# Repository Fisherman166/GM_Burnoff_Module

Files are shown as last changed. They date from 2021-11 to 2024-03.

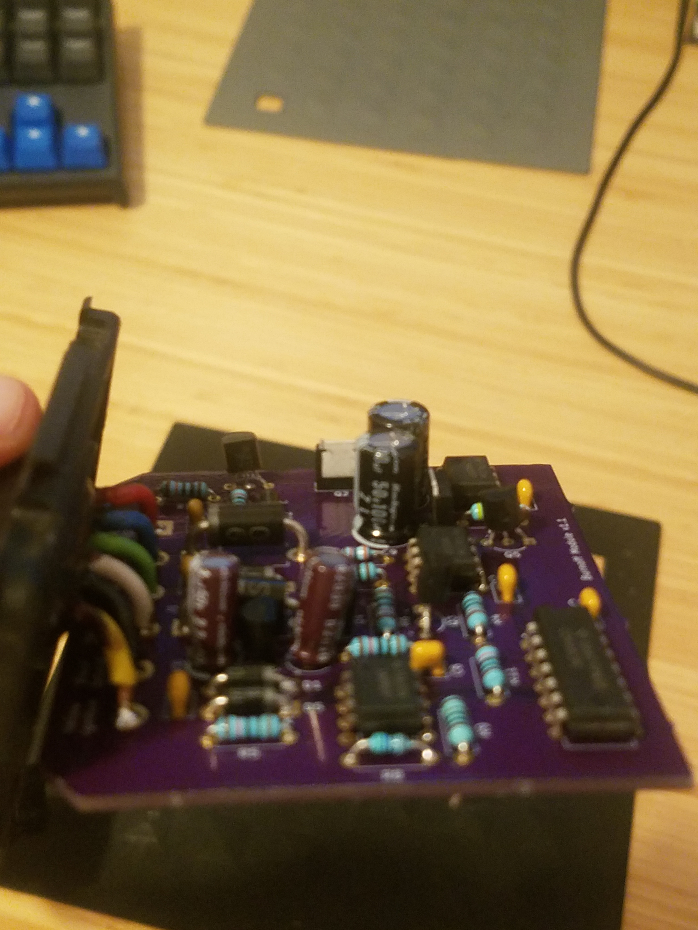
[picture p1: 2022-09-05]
pcb_pictures/20211124_192138.jpg

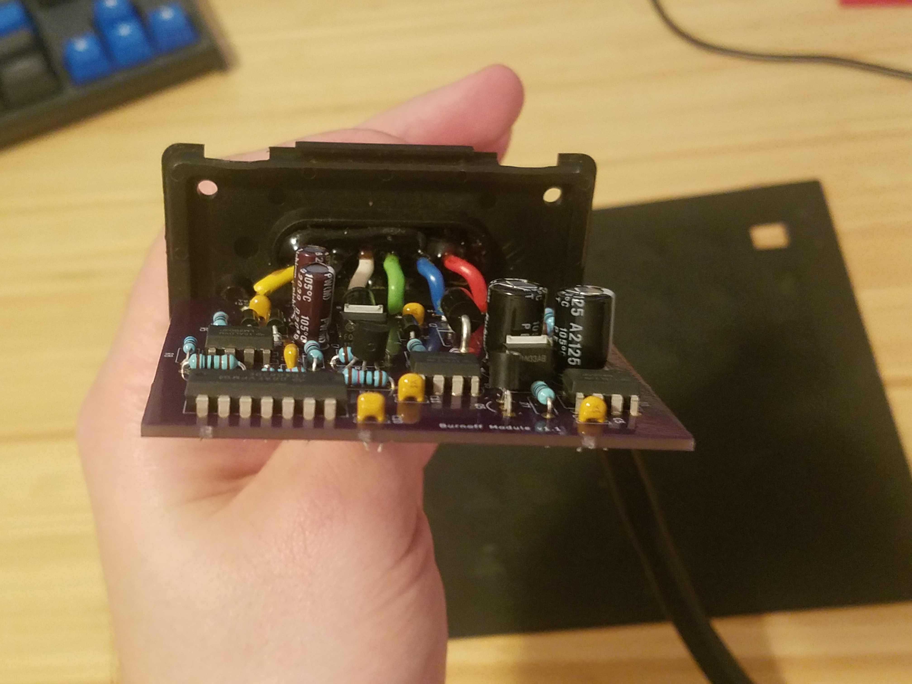
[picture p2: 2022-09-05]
pcb_pictures/20211124_192143.jpg

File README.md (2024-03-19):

# GM Burnoff Module

This repository includes a circuit which mimics the OEM burnoff module functionality. Burnoff modules are found in 1985 GM TPI cars including Corvette, Camaro, and Firebird. Feel free to modify this circuit as you see fit - I don't claim to be an analog eletronics expert.

**NOTE:  As far as I know this circuit should work as intended. Measurements from a working burnoff module in a car and the specifications from the repair manual match the design output. With that said, its never been tested in a real car, and has only been tested on a testbench. So use it at your own risk. I do not take any responsbility for any damage done.**

## Overview
* Building_your_pcb.odt - Tutorial style document which describes how to use this repository to build your own replacement burnoff module.
* OEM_Burnoff_Module_Specification.odt - Document which describes the OEM burnoff module functionality in detail.
* Design_Document.odt - Document which describes both the why and how design decisions were made for the replacement circuit.

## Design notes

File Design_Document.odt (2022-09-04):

Replacement Burnoff Module Design

By: Sean Koppenhafer

# General Information

This circuit was designed for input supply voltages on Battery+ up to 15V. All parts have at least a -40C to 105C temperature rating.

The ignition and serial input pins are protected by standard diodes. The MAF PWR and Burnoff Signal output pins are protected by schottky diodes. Battery+ is protected by the pmos high side switch. Ground is the only pin not protected by a diode or transistor.

All input pins, aside from ground, have a 0.1uF bypass capacitor. All ICs have the same 0.1uF bypass capacitors next to their supplies.

The unused second circuit on the AND gate has all of its inputs tied to ground and its output unconnected.

# PIN F – MAF Power Control

From the OEM spec we know this pin needs to be on whenever the ignition is on, and for roughly five seconds after the ignition is turned off. At a high level this breaks down into a high side switch to control PIN F through a timer circuit. The switch is controlled both by the ignition being being on and some sort of timer that holds the switch on after ignition drops. For the timer circuit a classic IC, the 555 timer, was used.

## High-Side Switching

A high side switch using a pmos and a nmos transistor in combination with a pullup resistor on the pmos gate was used. The circuit controls the gate of the nmos transistor to turn the pmos on/off. The pmos can then supply battery+ (Pin A) to MAF PWR (Pin F) and also provide a switched supply for the rest of the circuit. Using a switched voltage source not just for MAF PWR (Pin F), but for the entire circuit, this design achieves a current draw of 19uA when off according to LTSpice simulation.

The nmos gate is controlled both by ignition (Pin B) and the output of the five second 555 timer. Because the switched supply powers the rest of the circuit, we cannot have a glitch between when ignition (Pin B) goes low and the 555 timer output goes high. To solve this, the 555 timer output and ignition (Pin B) are on at the same time. When ignition (Pin B) goes high, the 555 timer output also goes high. When ignition (Pin B) goes low, the 555 timer keeps the switch on for five seconds before turning the switch off.

## Five Second Timer

After ignition (Pin B) goes from high to low (12V → 0V), we need MAF PWR (Pin F) to stay high for five seconds. A 555 timer is a simple, well-known IC that implements a timer. In the monostable configuration we can achieve a five second delay using a 47k resistor and a 100uF capacitor. Unfortunately, the delay begins on the negative edge of the trigger signal in the standard monostable 555 configuration, which is a problem. I needed to find a way to move the delay to the positive edge of the trigger signal so that I could pull trigger low the entire time ignition was on to ensure there would be no glitches on the switched supply.

Thanks to user bunky_bunk on Reddit, I was able to find a solution. Tying the threshold and trigger signals together to the RC network, then adding a nmos controlled by ignition (Pin B), which bypassed the 100uF capacitor, solved the problem. When ignition (Pin B) is on, the nmos is on, which bypasses the 100uF capacitor and pulls trigger/threshold to ground. This turns the 555 timer on. When ignition (Pin B) turns off, the nmos turns off, connecting the 100uF capacitor to trigger/threshold. As the capacitor charges, the voltage rises above the off threshold of the 555 timer after roughly 5.17 seconds, turning the 555 timer off.

# PIN D – Burnoff Signal Control

Controlling the burnoff signal is more difficult than MAF PWR. The same high side switch circuit could be reused, as could a 555 timer to control the delay. More control logic to control the switch was required though, which lead to much of the circuits complexity detailed below.

## Timer Control Logic

A two circuit comparator IC was used to determine when ignition (Pin B) was low and when we were in closed vs open loop. To create a constant reference voltage, a 5v linear regulator is used. If ignition is less than 5v, then the output of the comparator is high. A voltage divider off of the 5v supply was used to create a 3.2V reference voltage for the serial (Pin C) comparator. If the Serial pin is below 3.2v, the comparator output is high.

An AND gate is used to create a ‘do a burnoff cycle’ signal. If both outputs of the comparator are high (ignition is off and we are in closed loop), then we should do a burnoff cycle.

## On-After Four Second Delay Timer

LearnElectronics (https://youtu.be/bdZ9r2Ok0LE) from YouTube gave me the base “on-after delay” circuit. A 39k resistor with a 100uF capacitor creates roughly a four second delay. For a while I struggled with how to enable the delayed timer and also how to turn the timer off since the base circuit never turns the timer off. Using the same principle from the five second timer, bypassing the capacitor in the RC network and holding the trigger pin high would allow me to not start the delay until a burnoff was requested by the AND gate. A pmos was used to bypass the capacitor, which works perfectly, since the pmos would be on (bypassing the capacitor) when the AND gate is low, and the pmos would be off when the AND gate is high (allow the delay to start).

Because the 555 timer is on the same switched supply as the rest of the circuit, the other 555 timer actually turns this timer off. Relying on the other timer to switch things off after five seconds created the staggered burnoff signal: off for four seconds, on for one second, and then off when the other 555 timer shuts off.

# Waveforms

Waveforms were captured and compared for the same scenarios captured in the OEM specification document to ensure design correctness. All waveforms were captured using 5V per vertical division and 1 second per horizontal division. The top (yellow) signal is tracing the ignition input, the middle (blue) signal is tracing the MAF Power output, and the bottom (purple) signal is tracing the burnoff signal output. The serial input is not shown in the waveform but is being manipulated on the testbench to create open/closed loop scenarios.

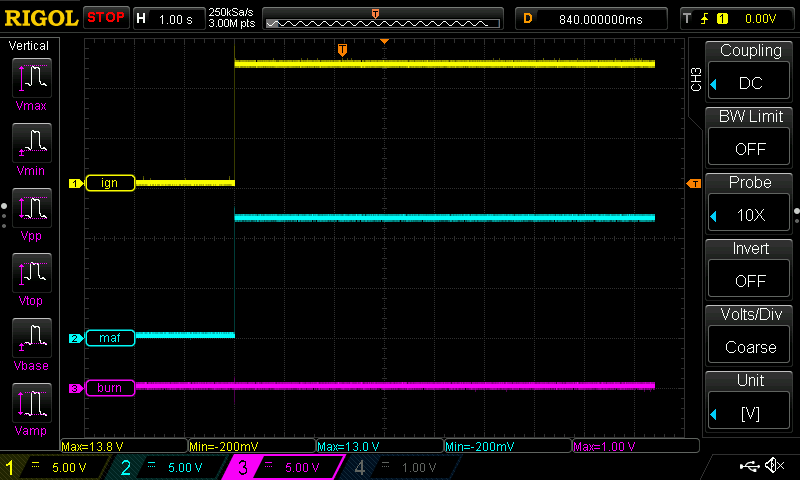
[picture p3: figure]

Fig 1-1: My Burnoff Module When Ignition Turns On

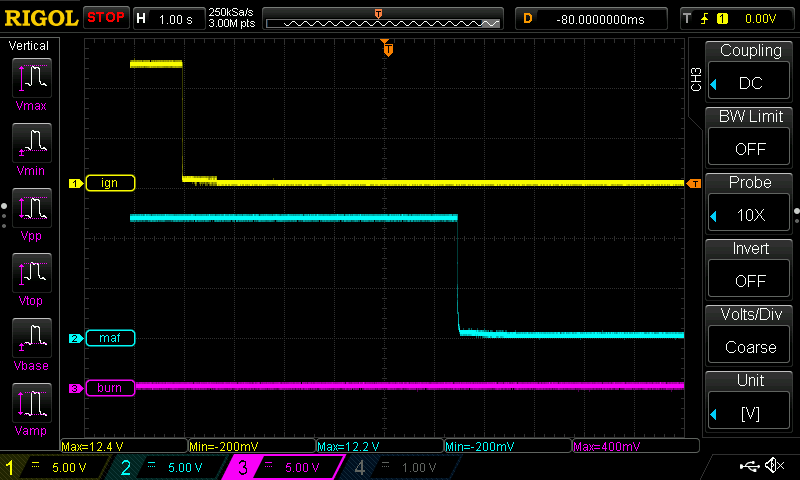
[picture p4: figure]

Fig 1-2: My Burnoff Module When Ignition Turns Off In Open Loop (No Burnoff)

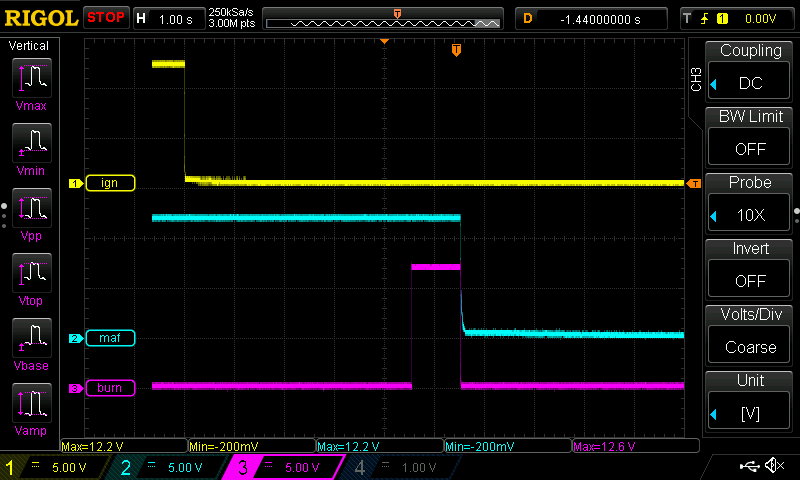
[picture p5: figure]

Fig 1-3: My Burnoff Module When Ignition Turns Off In Closed Loop (Burnoff)

# Results

My design keeps MAF PWR high for roughly 5.5 seconds versus 5 seconds in the OEM part. My design keeps a 1 second burnoff time by starting at 4.5 seconds instead of 4 seconds in the OEM part. Otherwise, my designs waveforms mimic the OEM design exactly with the exception of the extra half second time shift.

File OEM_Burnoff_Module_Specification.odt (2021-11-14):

OEM Burnoff Module Specification

By: Sean Koppenhafer

# Interface Connections

Black box testing was used on a known-good OEM burnoff module to create this operation specification. Measurements for input signals were taken from a 1985 Corvette. Output measurements were taken both in the car and on a testbench.

Connector Pin | Wire Color | Name | Type | Description
A | Red | Battery+ | Input | Voltage varies depending on battery+ voltage. ~11.8V→14.7V
B | Yellow | Ignition | Input | 12V when ignition on, 0V (GND) when ignition off.
C | Green | Serial | Input | ~5V when car turns off in open loop. ~2.5V when car turns off in closed loop.
D | White | Burnoff Signal | Output | Supplies battery+ to burnoff input of MAF.
E | Black | Ground (GND) | Input | Engine ground for the burnoff module.
F | Blue | MAF Power | Output | Supplies battery+ to MAF.

Table 1-1: Burnoff Module Connector

# OEM Burnoff Module Waveforms

Driving the input wires on the testbench in accordance with the measurements defined above in Table 1-1, these waveforms were captured using an oscilloscope. All waveforms were captured using 5V per vertical division and 1 second per horizontal division. The top (yellow) signal is tracing the ignition input, the middle (blue) signal is tracing the MAF Power output, and the bottom (purple) signal is tracing the burnoff signal output. The serial input is not shown in the waveform but is being manipulated on the testbench to create open/closed loop scenarios.

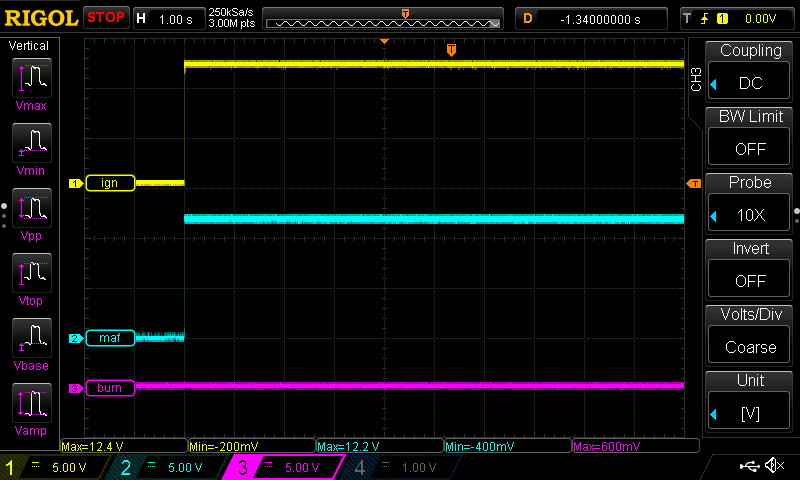
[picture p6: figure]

Fig 1-1: OEM Burnoff Module When Ignition Turns On

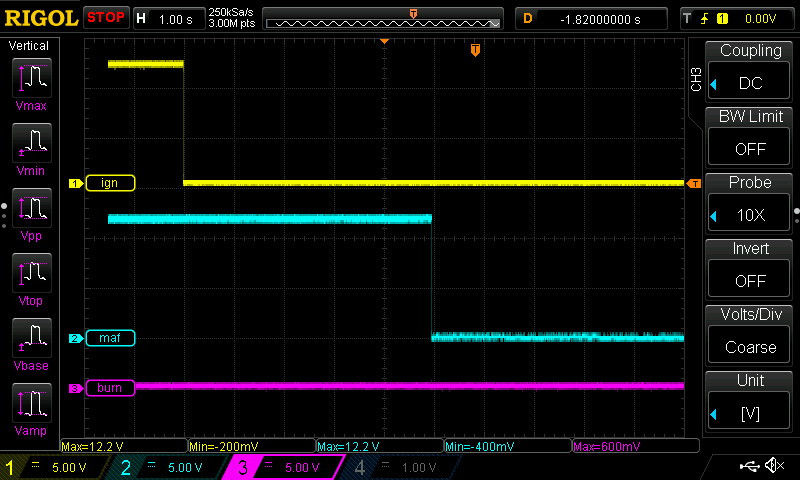
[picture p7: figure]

Fig 1-2: OEM Burnoff Module When Ignition Turns Off In Open Loop (No Burnoff)

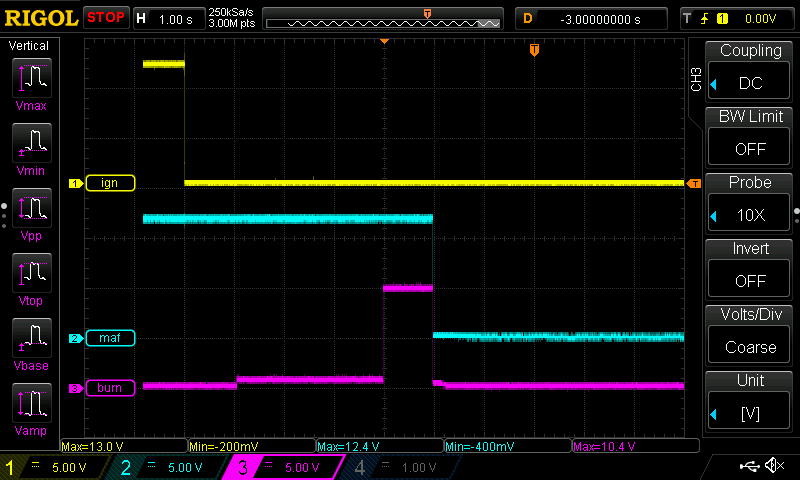
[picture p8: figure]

Fig 1-3: OEM Burnoff Module When Ignition Turns Off In Closed Loop (Burnoff)

# Operation Specification

- When ignition (Pin B) is on (+12V), supply battery+ (Pin A) to MAF Power (Pin F). Burnoff Signal (Pin D) is off.
- When ignition (Pin B) transitions from +12V to GND (AKA the car is turned off), a few things can occur.
  - Battery+ (Pin A) always continues to be supplied to MAF Power (Pin F) for five seconds before turning off regardless if the car was in open or closed loop.
  - If the car was in open loop when turned off, the Serial (Pin C) input will go to 5V. Keep the Burnoff signal (Pin D) off.
  - If the car was in closed loop when turned off, the Serial (Pin C) input will go to 2.5V. Wait four seconds, then supply battery+ (Pin A) to the Burnoff Signal (Pin D) for one second. The burnoff signal (Pin D) should go high while MAF Power (Pin F) is still high.

In either open or closed loop, the burnoff module should pull zero current five seconds after ignition goes low.

# PCB Dimensions

2.64 inches wide. Wire holes are 0.25 inches apart.

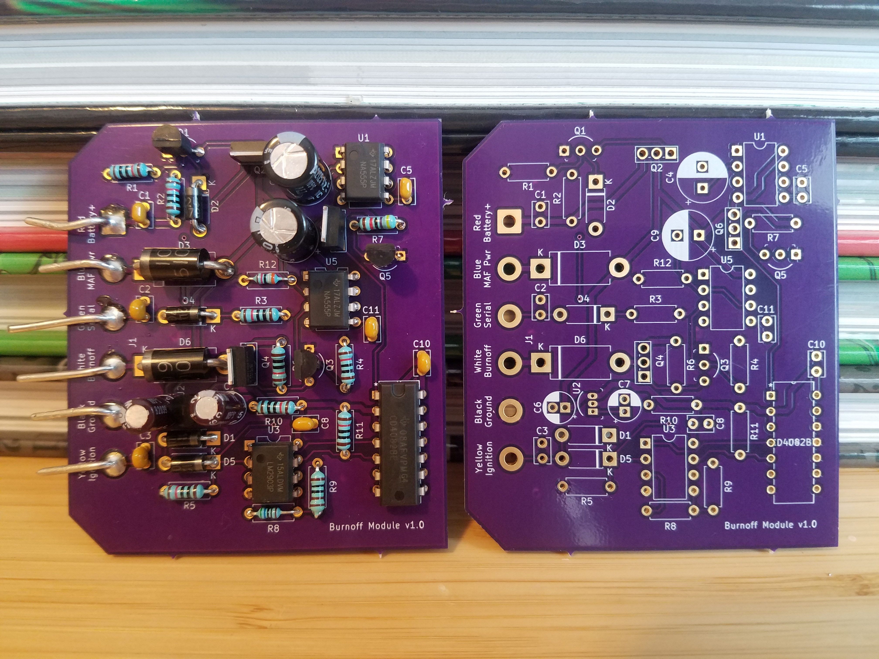
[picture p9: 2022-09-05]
pcb_pictures/v1.0_front.jpg

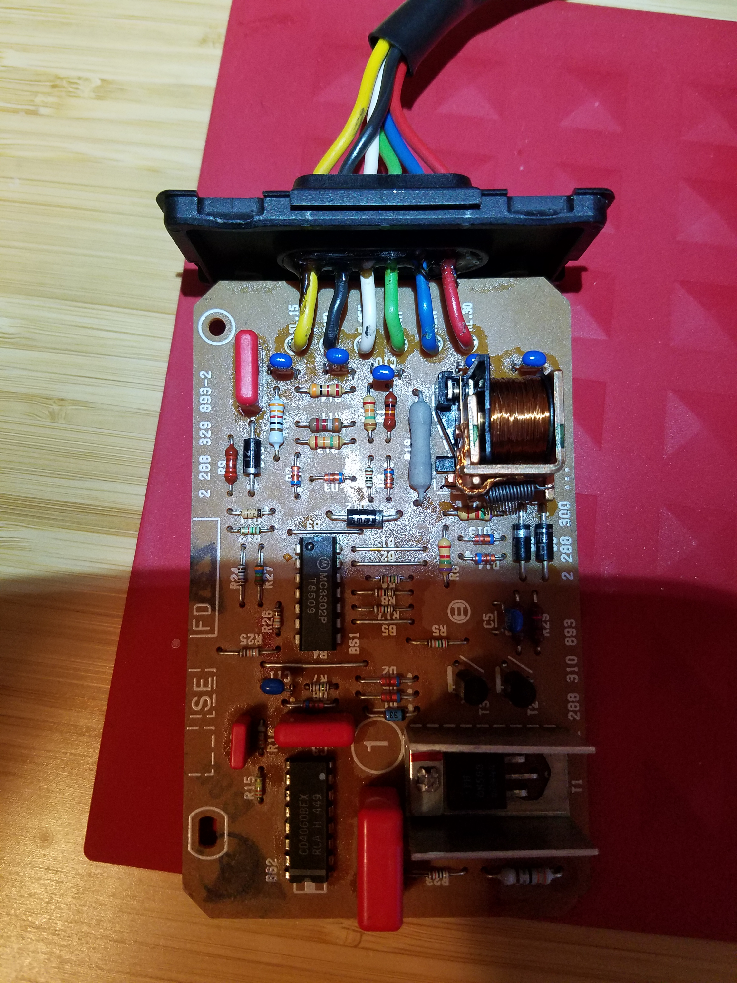
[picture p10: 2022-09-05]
pcb_pictures/OEM.jpg

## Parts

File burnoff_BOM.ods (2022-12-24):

Reference | Quantity | Value | Footprint | MPN | Price | Total Price | Part Link
C1 C2 C3 C5 C8 C10 C11 | 7 | 0.1uF | Capacitor_THT:C_Rect_L4.0mm_W2.5mm_P2.50mm | K104K15X7RF53L2 | $0.28 | $1.96 | https://www.digikey.com/en/products/detail/vishay-beyschlag-draloric-bc-components/K104K15X7RF53L2/2820506
C4 C9 | 2 | 100uF | Capacitor_THT:CP_Radial_D8.0mm_P3.50mm | 50ZL100MEFC8X11.5 | $0.44 | $0.88 | https://www.digikey.com/en/products/detail/rubycon/50ZL100MEFC8X11-5/3563372
C6 C7 | 2 | 2.2uF | Capacitor_THT:CP_Radial_D5.0mm_P2.00mm | UPW1H2R2MDD | $0.30 | $0.60 | https://www.digikey.com/en/products/detail/nichicon/UPW1H2R2MDD/589628
D1 D2 D4 D5 | 4 | D | Diode_THT:D_DO-41_SOD81_P7.62mm_Horizontal | 1N4007G-T | $0.30 | $1.20 | https://www.digikey.com/en/products/detail/diodes-incorporated/1N4007G-T/160652
D3 D6 | 2 | D_Schottky | Diode_THT:D_DO-201AD_P12.70mm_Horizontal | SB5100-T | $0.74 | $1.48 | https://www.digikey.com/en/products/detail/diodes-incorporated/SB5100-T/278636
Q2 Q4 Q6 | 3 | Q_PMOS_GDS | Package_TO_SOT_THT:TO-251-3_Vertical | IRFU9024NPBF | $0.99 | $2.97 | https://www.digikey.com/en/products/detail/infineon-technologies/IRFU9024NPBF/812405
Q1 Q3 Q5 | 3 | Q_NMOS_SGD | digikey-footprints:TO-92-3_Formed_Leads | 2N7000TA | $0.46 | $1.38 | https://www.digikey.com/en/products/detail/onsemi/2N7000TA/3042479?s=N4IgTCBcDa4HIHYAMKAqBBAwqgtHAIiALoC%2BQA
R12 | 1 | 39k | Resistor_THT:R_Axial_DIN0207_L6.3mm_D2.5mm_P7.62mm_Horizontal | RNMF14FTC39K0 | $0.10 | $0.10 | https://www.digikey.com/en/products/detail/stackpole-electronics-inc/RNMF14FTC39K0/2617339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
R1 R2 R3 R4 R5 R6 R10 R11 | 8 | 10k | Resistor_THT:R_Axial_DIN0207_L6.3mm_D2.5mm_P7.62mm_Horizontal | RNF14FTD10K0 | $0.10 | $0.80 | https://www.digikey.com/en/products/detail/stackpole-electronics-inc/RNF14FTD10K0/1706596
R7 | 1 | 47k | Resistor_THT:R_Axial_DIN0207_L6.3mm_D2.5mm_P7.62mm_Horizontal | RNF14FTD47K0 | $0.10 | $0.10 | https://www.digikey.com/en/products/detail/stackpole-electronics-inc/RNF14FTD47K0/1682294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
R8 | 1 | 560 | Resistor_THT:R_Axial_DIN0207_L6.3mm_D2.5mm_P7.62mm_Horizontal | RNMF14FTC560R | $0.10 | $0.10 | https://www.digikey.com/en/products/detail/stackpole-electronics-inc/RNMF14FTC560R/2617360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
R9 | 1 | 1k | Resistor_THT:R_Axial_DIN0207_L6.3mm_D2.5mm_P7.62mm_Horizontal | RNF14FTD1K00 | $0.10 | $0.10 | https://www.digikey.com/en/products/detail/stackpole-electronics-inc/RNF14FTD1K00/1706678
U1 U5 | 2 | NA555P | Package_DIP:DIP-8_W7.62mm | NA555P | $0.50 | $1.00 | https://www.digikey.com/en/products/detail/texas-instruments/NA555P/1571935
U2 | 1 | LP2950-5.0_TO92 | digikey-footprints:TO-92-3 | LP2950CZ-5.0/NOPB | $0.93 | $0.93 | https://www.digikey.com/en/products/detail/texas-instruments/LP2950CZ-5-0-NOPB/148222
U3 | 1 | LM2903 | Package_DIP:DIP-8_W7.62mm | LM2903P | $0.42 | $0.42 | https://www.digikey.com/en/products/detail/texas-instruments/LM2903P/372786
U4 | 1 | CD4082BE | footprints:CD4082BE | CD4082BE | $0.58 | $0.58 | https://www.digikey.com/en/products/detail/texas-instruments/CD4082BE/67325
 |  |  |  |  | Total Parts Cost: | $14.60
Archive - EOL Parts
Q2 Q4 Q6 | 3 | Q_PMOS_GDS | Package_TO_SOT_THT:TO-251-3_Vertical | FQU11P06TU | $0.92 | $2.76 | https://www.digikey.com/en/products/detail/onsemi/FQU11P06TU/1053688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

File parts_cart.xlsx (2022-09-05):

# | QUANTITY | PART NUMBER | MANUFACTURER PART NUMBER | DESCRIPTION | CUSTOMER REFERENCE | BACKORDER | UNIT PRICE | EXTENDED PRICE
1 | 10 | 296-21753-5-ND | NA555P | IC OSC SINGLE TIMER 100KHZ 8-DIP |  | 0 | 0.409 | 4.09
2 | 3 | 296-2067-5-ND | CD4082BE | IC GATE AND 2CH 4-INP 14DIP |  | 0 | 0.58 | 1.74
3 | 10 | KSC1845FTACT-ND | KSC1845FTA | TRANS NPN 120V 0.05A TO-92 |  | 0 | 0.3 | 3.00
4 | 10 | 2N7000TACT-ND | 2N7000TA | MOSFET N-CH 60V 200MA TO92-3 |  | 0 | 0.343 | 3.43
5 | 4 | FQU11P06TU-ND | FQU11P06TU | MOSFET P-CH 60V 9.4A IPAK |  | 0 | 0.92 | 3.68
6 | 4 | 296-34316-5-ND | TL972IP | IC OPAMP GP 2 CIRCUIT 8DIP |  | 0 | 0.96 | 3.84
7 | 10 | SB5100DICT-ND | SB5100-T | DIODE SCHOTTKY 100V 5A DO201AD |  | 0 | 0.653 | 6.53
8 | 10 | 1N4007GDICT-ND | 1N4007G-T | DIODE GEN PURP 1KV 1A DO41 |  | 0 | 0.248 | 2.48
9 | 3 | LP2950CZ-5.0/NOPB-ND | LP2950CZ-5.0/NOPB | IC REG LINEAR 5V 100MA TO92-3 |  | 0 | 0.93 | 2.79

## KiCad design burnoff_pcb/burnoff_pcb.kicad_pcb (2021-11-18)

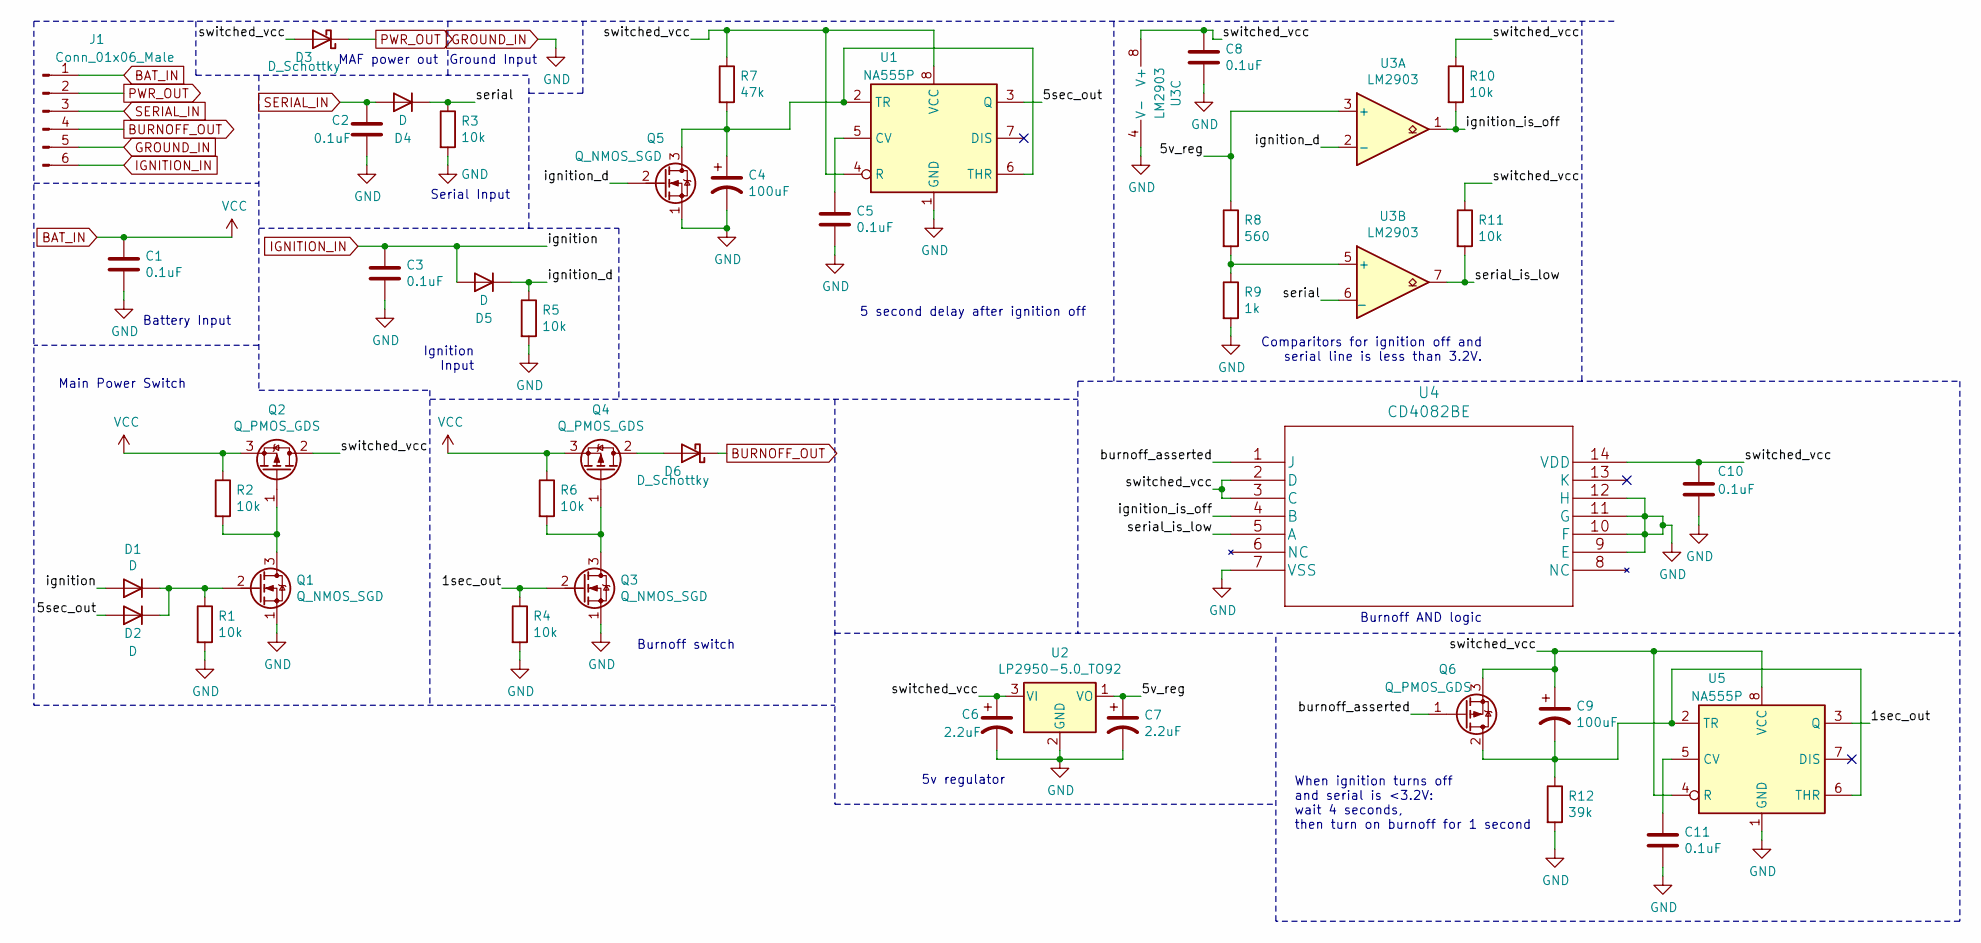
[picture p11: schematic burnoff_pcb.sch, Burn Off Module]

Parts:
C1, C2, C3, C5, C8, C10, C11: 0.1uF; C_Rect_L4.0mm_W2.5mm_P2.50mm
C4, C9: 100uF; CP_Radial_D8.0mm_P3.50mm
C6, C7: 2.2uF; CP_Radial_D5.0mm_P2.00mm
D1, D2, D4, D5: D; D_DO-41_SOD81_P7.62mm_Horizontal
D3, D6: D_Schottky; D_DO-201AD_P12.70mm_Horizontal
J1: Conn_01x06_Male; SolderWire-1.5sqmm_1x06_P7.8mm_D1.7mm_OD3.9mm
Q1, Q3, Q5: Q_NMOS_SGD; TO-92-3_Formed_Leads
Q2, Q4, Q6: Q_PMOS_GDS; TO-251-3_Vertical
R1, R2, R3, R4, R5, R6, R10, R11: 10k; R_Axial_DIN0207_L6.3mm_D2.5mm_P7.62mm_Horizontal
R7: 47k; R_Axial_DIN0207_L6.3mm_D2.5mm_P7.62mm_Horizontal
R8: 560; R_Axial_DIN0207_L6.3mm_D2.5mm_P7.62mm_Horizontal
R9: 1k; R_Axial_DIN0207_L6.3mm_D2.5mm_P7.62mm_Horizontal
R12: 39k; R_Axial_DIN0207_L6.3mm_D2.5mm_P7.62mm_Horizontal
U1, U5: NA555P; DIP-8_W7.62mm
U2: LP2950-5.0_TO92; TO-92-3
U3: LM2903; DIP-8_W7.62mm
U4: CD4082BE

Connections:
/1sec_out: Q3.2 (G), R4.1, U5.3 (Q)
/5sec_out: D2.2 (A), U1.3 (Q)
/5v_reg: C7.1, R8.1, U2.1 (VO), U3.3 (+)
/burnoff_asserted: Q6.1 (G), U4.1 (J)
/ignition_d: D5.1 (K), Q5.2 (G), R5.1, U3.2 (-)
/ignition_is_off: R10.2, U3.1, U4.4 (B)
/serial: D4.1 (K), R3.1, U3.6 (_)
/serial_is_low: R11.2, U3.7, U4.5 (A)
/switched_vcc: C6.1, C8.1, C9.1, C10.1, D3.2 (A), Q2.2 (D), Q6.3 (S), R7.1, R10.1, R11.1, U1.4 (R), U1.8 (VCC), U2.3 (VI), U3.8 (V+), U4.2 (D), U4.3 (C), U4.14 (VDD), U5.4 (R), U5.8 (VCC)
BAT_IN: C1.1, J1.1, Q2.3 (S), Q4.3 (S), R2.1, R6.1
BURNOFF_OUT: D6.1 (K), J1.4
GROUND_IN: C1.2, C2.2, C3.2, C4.2, C5.2, C6.2, C7.2, C8.2, C10.2, C11.2, J1.5, Q1.1 (S), Q3.1 (S), Q5.1 (S), R1.2, R3.2, R4.2, R5.2, R9.2, R12.2, U1.1 (GND), U2.2 (GND), U3.4 (V-), U4.7 (VSS), U4.9 (E), U4.10 (F), U4.11 (G), U4.12 (H), U5.1 (GND)
IGNITION_IN: C3.1, D1.2 (A), D5.2 (A), J1.6
unnamed: C4.1, Q5.3 (D), R7.2, U1.2 (TR), U1.6 (THR)
unnamed: C5.1, U1.5 (CV)
unnamed: C9.2, Q6.2 (D), R12.1, U5.2 (TR), U5.6 (THR)
unnamed: C11.1, U5.5 (CV)
unnamed: D1.1 (K), D2.1 (K), Q1.2 (G), R1.1
unnamed: D6.2 (A), Q4.2 (D)
unnamed: Q1.3 (D), Q2.1 (G), R2.2
unnamed: Q3.3 (D), Q4.1 (G), R6.2
unnamed: R8.2, R9.1, U3.5 (+)
PWR_OUT: D3.1 (K), J1.2
SERIAL_IN: C2.1, D4.2 (A), J1.3

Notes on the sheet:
Main Power Switch
Battery Input
MAF power out
Serial Input
Ground Input
Ignition Input
Burnoff switch
5 second delay after ignition off
5v regulator
Comparitors for ignition off and serial line is less than 3.2V.
Burnoff AND logic
When ignition turns off and serial is <3.2V: wait 4 seconds, then turn on burnoff for 1 second

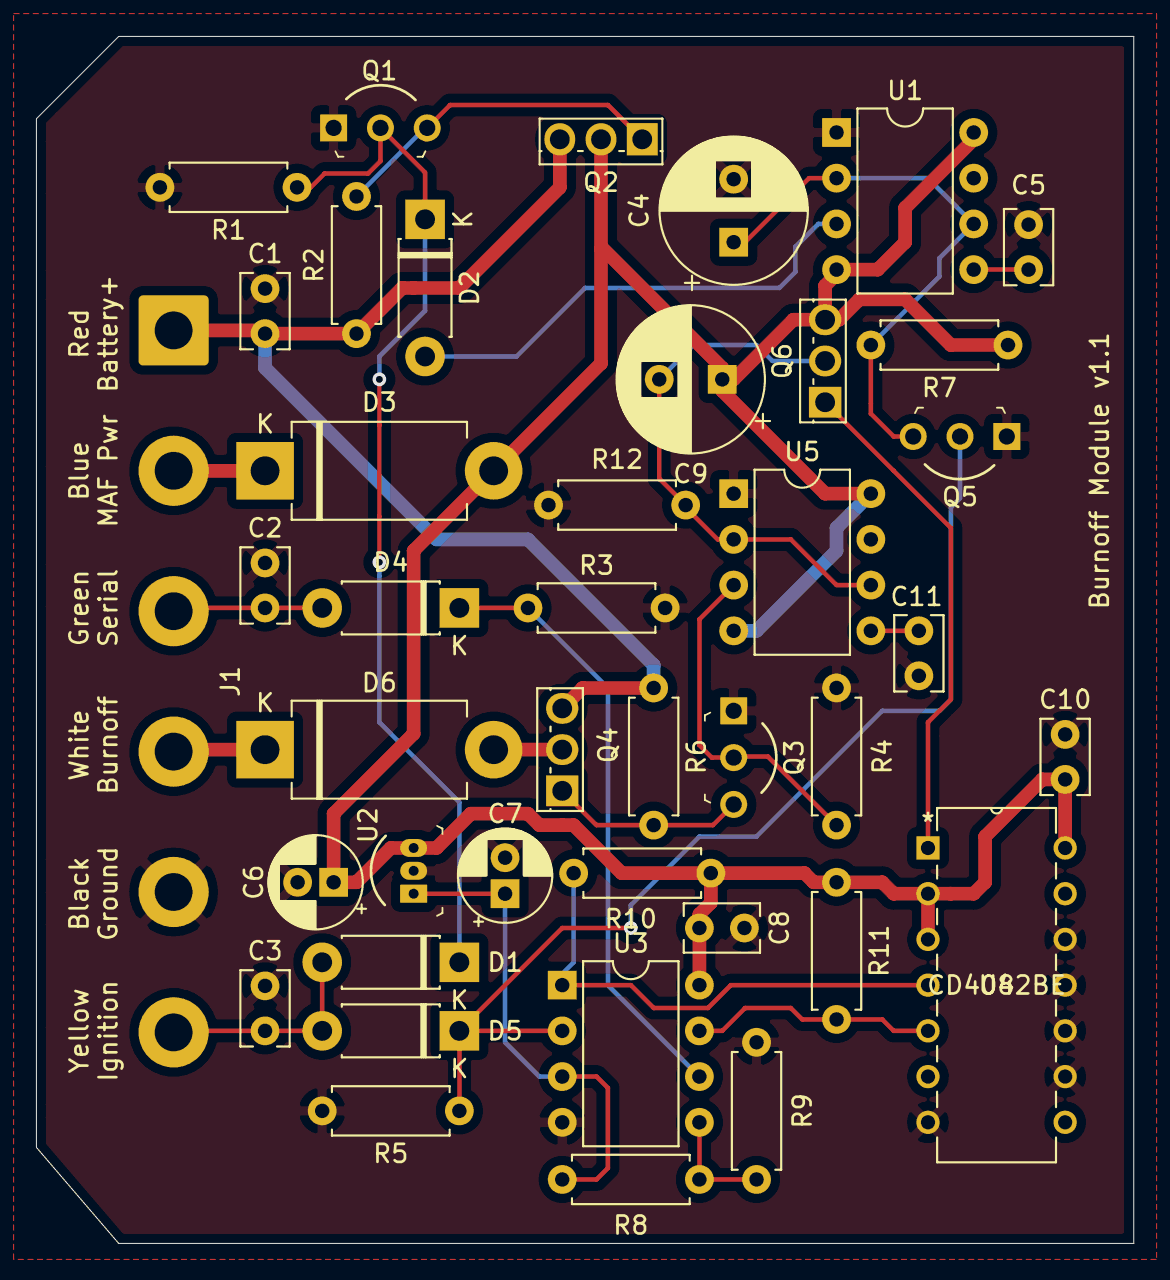
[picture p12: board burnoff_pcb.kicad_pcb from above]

Board: 2 copper layers, 61.0 x 67.1 mm, 41 parts (0 on the bottom side), 24 nets.

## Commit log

2021-10-30 Initial commit of v1.0 of the pcb.
    [burnoff_BOM.ods, burnoff_pcb.csv, burnoff_pcb.kicad_pcb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]
2021-11-14 Revision v1.1 of the board.
    [burnoff_pcb.kicad_pcb, burnoff_pcb.sch]
2021-11-14 Remove csv version of BOM.
    [burnoff_pcb.csv]
2021-11-18 Update to version v1.1 of the schematic/pcb layout.
    [burnoff_pcb.kicad_pcb, burnoff_pcb.sch]
2022-09-05 Add pictures of PCB
2022-09-05 Add document to explain building the PCB.
    [parts_cart.xlsx]
2022-12-24 Updated BOM with new p-channel MOSFET as original one is EOL at the end of 2022.
    [burnoff_BOM.ods]

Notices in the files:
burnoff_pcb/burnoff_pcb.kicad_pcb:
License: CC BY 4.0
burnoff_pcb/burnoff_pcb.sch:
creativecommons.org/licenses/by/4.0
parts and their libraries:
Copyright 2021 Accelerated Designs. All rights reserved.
